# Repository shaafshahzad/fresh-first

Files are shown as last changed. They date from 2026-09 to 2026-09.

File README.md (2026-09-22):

# Fresh First

Fresh First is a phone-friendly fridge expiry tracker and low-power display
platform deployed on Vercel. Capture groceries naturally with phrases such as
`Milk tomorrow` or `Bread Sep 4`; Fresh First parses the dates and keeps the
list ordered from the soonest expiry to the latest.

[Try the web app](https://fresh-first.vercel.app) ·
[Read the build story](https://www.shaafshahzad.com/blog/fresh-first)

## Screenshots

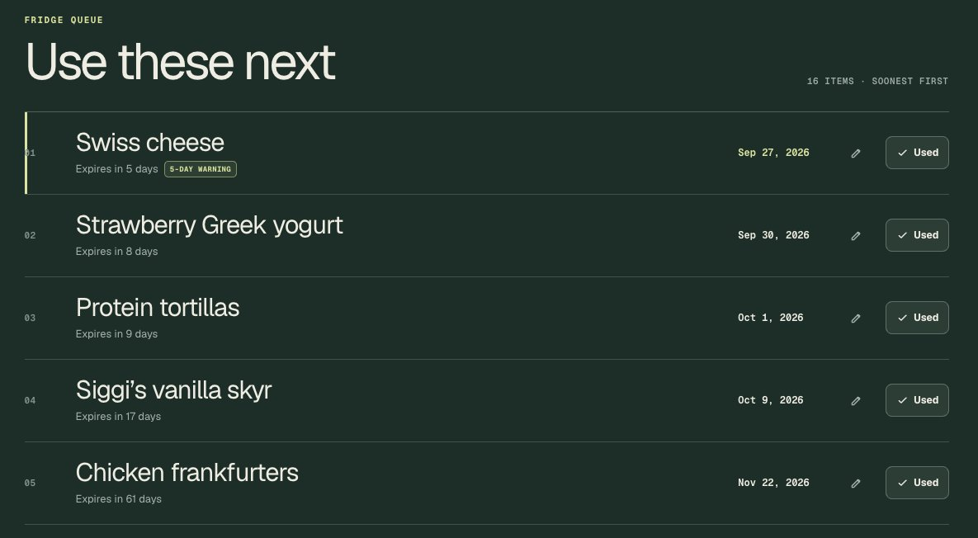
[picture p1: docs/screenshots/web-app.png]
Fresh First web app showing groceries ordered by expiry date


| Working e-paper display | Finished prototype |
| --- | --- |
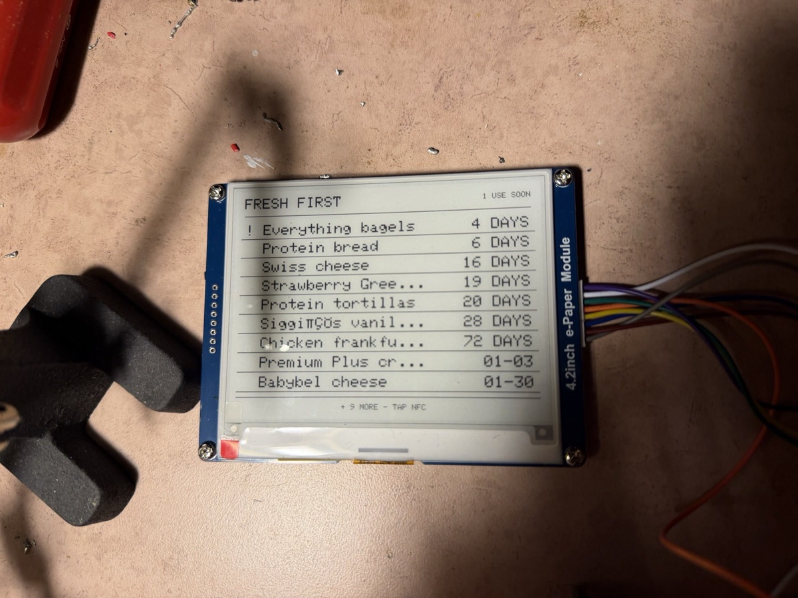
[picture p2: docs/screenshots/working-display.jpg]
Working Fresh First e-paper display showing an expiry-sorted grocery list
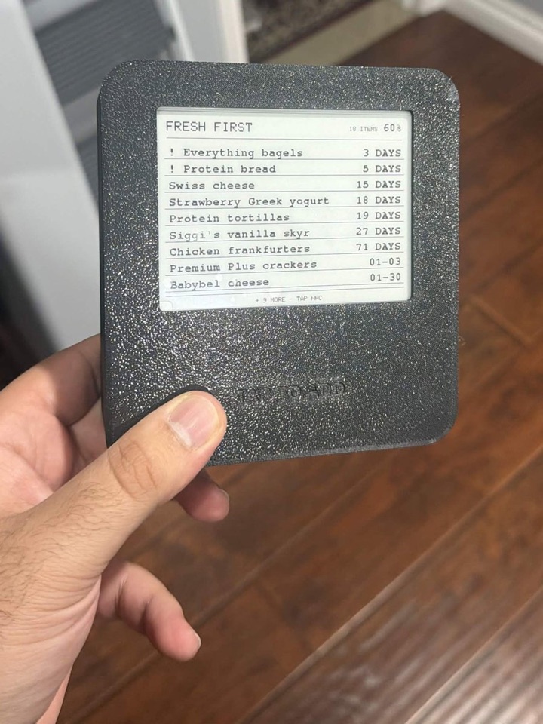
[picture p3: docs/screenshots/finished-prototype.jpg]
Finished Fresh First prototype in its 3D-printed enclosure
|  |  |

## Current MVP

- Natural-language quick capture with one item per line
- Continuous cross-browser voice capture with pause-based item separation
- Local Whisper transcription during development, including Helium support
- Batch entry for several groceries at once
- Exact product-name and date fields as a fallback
- Durable Neon Postgres storage connected through Vercel
- Email/password customer accounts with private, account-scoped fridge data
- Physical display provisioning and short-lived code pairing
- NFC handoff that opens the correct customer fridge on a phone
- Authenticated, ETag-enabled JSON feed for low-power e-paper firmware
- Automatic expiry sorting
- Clear expired, use-now, really-soon, and five-day warning states
- One-tap “Used” removal with retained history
- Inline product-name and expiry-date correction with automatic re-sorting
- Responsive management view at `/`
- Auto-refreshing fridge view at `/display`
- Customer display preview at `/display`
- Hardware feed at `/api/device/{deviceId}/feed`

Quick capture understands `today`, `tomorrow`, `Friday`, `next Friday`,
`in 3 days`, `+3 days`, `Sep 4`, `4 Sep`, `9/4`, and ISO dates.

Start a voice session once, say one product and expiry date, pause briefly, and
continue with the next item. Development audio is transcribed locally by
whisper.cpp. A deployed instance can use `OPENAI_API_KEY` directly or the
project's Vercel AI Gateway identity; recorded phrases are processed in memory
and are not stored by Fresh First.

## Development

Requirements: Node.js 22.13 or newer. Local voice transcription also requires
`ffmpeg`, `whisper-cpp`, and a compatible GGML Whisper model.

- Install dependencies: `bun install`
- Pull development variables: `vercel env pull .env.local`
- Prepare the database: `bun run db:migrate`
- Set `BETTER_AUTH_SECRET` to a high-entropy secret before production
- Load relative-date development examples: `bun run db:seed:mock`
- Provision a simulated or physical display: `bun run device:provision -- "Kitchen display"`
- Start locally: `bun run dev`
- Optional local voice model: set `WHISPER_MODEL_PATH` and
  `WHISPER_CLI_PATH` (the macOS defaults are detected automatically)
- Run checks: `bun run lint`, `bun run test`, and `bun run build`
- Deploy: `vercel --prod --yes`

The physical-device contract and NFC lifecycle are documented in
[`docs/device-protocol.md`](docs/device-protocol.md).

## Privacy

The GitHub repository is private. Customer data is separated by account,
device feeds require per-unit secrets, and pairing codes expire after 30
minutes. Environment files and database credentials are ignored by Git.

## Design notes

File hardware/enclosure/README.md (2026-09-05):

# Fresh First 4.2-inch e-paper enclosure

This is a two-piece, parameterized OpenSCAD case for the Waveshare 4.2-inch
400 × 300 e-paper module. It provides:

- a rear-loading pocket for the 103 × 78.5 mm display PCB;
- a flush removable rear cover;
- four protected pockets for 20 × 3 mm disc magnets;
- a front-facing 32.5 × 32.5 mm pocket for a 30 × 30 mm NFC tag;
- an internal cavity for a small ESP32 board and wiring; and
- a generous right-side USB/cable service opening.

The assembled shell is approximately **120 × 129.5 × 16.8 mm**. The display
window is 86.2 × 64.8 mm. All important fit values are grouped at the top of
`fresh-first-case.scad` so they can be adjusted after the physical parts arrive.

The model targets the exact module in the prototype order:

- [Waveshare 4.2-inch e-paper module on Amazon Canada](https://www.amazon.ca/dp/B074NR1SW2)
- [Waveshare module specification](https://www.waveshare.com/product/ai/displays/e-paper/4.2inch-e-paper-module.htm)

## Files

- `fresh-first-case.scad` — editable source and exploded assembly preview
- `output/fresh-first-front.stl` — front shell
- `output/fresh-first-back.stl` — magnetized rear cover
- `output/fresh-first-magnet-test.stl` — quick pocket-clearance test
- `output/fresh-first-case-preview.png` — rendered exploded interior preview
- `output/fresh-first-product-preview.png` — rendered product-front preview

## Hardware

- Waveshare 4.2-inch E-Paper Module, 103 × 78.5 mm PCB
- 4 × 20 × 3 mm neodymium disc magnets ([8-pack used for this design](https://www.amazon.ca/dp/B09XJ5JFFX))
- 1 × ferrite-backed/on-metal NFC tag, no larger than 30 × 30 × 1 mm
- 4 × M2.5 × 8 mm countersunk self-tapping screws
- thin EVA/foam dots for the four PCB corners
- two-part epoxy or E6000-style flexible adhesive for the magnets

The current magnet pocket is **20.4 mm diameter × 3.2 mm deep**, with a 0.65 mm
printed skin between each magnet and the refrigerator. Print the fit-test part
first: magnet batches and printer calibration can vary. Increase
`magnet_d_clearance` in 0.1 mm steps if needed.

The linked magnet listing must have the **20x3mm 8Pcs-Silver** size selected.
Amazon may switch the selected variation when opening a product link, so verify
that exact size before ordering. Eight magnets provide four for the enclosure
and four spares for fit testing or a second revision.

Use an **on-metal or ferrite-backed NFC tag**. A plain sticker tag may become
unreliable when mounted near a steel refrigerator and four strong magnets. The
tag pocket is on the front lower chin to maximize separation from both.

## Export

From this directory:

```sh
openscad -o output/fresh-first-front.stl \
  -D 'part="front"' fresh-first-case.scad

openscad -o output/fresh-first-back.stl \
  -D 'part="back"' fresh-first-case.scad

openscad -o output/fresh-first-magnet-test.stl \
  -D 'part="magnet_test"' fresh-first-case.scad

openscad -o output/fresh-first-product-preview.png \
  --imgsize=1200,1200 --viewall --autocenter --projection=o \
  -D 'part="product_preview"' fresh-first-case.scad
```

## Print settings

- PETG recommended; PLA is fine for the first dimensional prototype.
- 0.20 mm layer height, 0.4 mm nozzle.
- 4 perimeters, 5 top/bottom layers, 20–30% gyroid infill.
- Print the front shell face-down and the rear cover fridge-side-down.
- No supports should be needed. Bridge the right-side service opening.

## Assembly

1. Print `fresh-first-magnet-test.stl` and confirm the magnet pocket before the
   full rear cover.
2. Dry-fit the display from the rear. Do not force the glass or flex cable.
3. Bond the NFC tag inside the lower front pocket, with its readable face aimed
   through the 0.8 mm front skin.
4. Mount the ESP32 and any battery with thin VHB/foam tape after confirming the
   exact purchased board and battery dimensions.
5. Put a thin foam dot on each PCB corner so the closed rear cover holds the
   module gently without flexing it.
6. Epoxy one magnet into each rear-cover pocket. Let the adhesive cure fully.
7. Close the case with four M2.5 × 8 mm countersunk self-tapping screws. Their
   heads must sit below the rear surface so they cannot scratch the fridge.

Do not print around installed magnets. Install them only after printing, and
keep loose neodymium magnets away from children, pets, magnetic cards, and
medical implants. They are brittle and can chip or pinch when allowed to snap
together.

## Fit notes before a production enclosure

This first version uses the manufacturer's PCB dimensions and allows extra
clearance for prototype wiring. Before a production print, measure the delivered
module's screen offset, rear component height, connector location, ESP32 board,
battery, screw heads, NFC tag, and magnets with calipers, then update the grouped
parameters at the top of the SCAD file.

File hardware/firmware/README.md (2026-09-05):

# Fresh First display firmware

This PlatformIO project powers the 30-pin ESP32 DevKit and Waveshare 4.2-inch
black/white V2 e-paper prototype. It provisions Wi-Fi through a phone-friendly
captive portal, securely fetches the paired fridge feed, refreshes the panel
only when its content changes, and sleeps between checks.

The fridge view shows the nine soonest-expiring items. When more items exist,
the footer reports the hidden count and directs the user to tap the NFC tag for
the complete list.

The monochrome Waveshare V2 panel used by this prototype has an SSD1683
controller and requires the `GxEPD2_420_GDEY042T81` driver. The older
UC8176-compatible `GxEPD2_420` driver can compile and transmit without errors,
but the V2 panel ignores those frames and retains its previous image.

## Wiring

Disconnect USB power before adding or moving wires.

| Display | ESP32 |
| --- | --- |
| VCC | 3V3 |
| GND | GND |
| DIN | D14 / GPIO14 |
| CLK | D13 / GPIO13 |
| CS | D15 / GPIO15 |
| DC | D27 / GPIO27 |
| RST | D26 / GPIO26 |
| BUSY | D25 / GPIO25 |

Leave the display module's `BS` resistor in its factory four-wire SPI position.

## Build and upload

Install PlatformIO once with a pip-capable tool environment:

```sh
uv tool install platformio --with pip
```

Then, from this directory:

```sh
platformio run
platformio run \
  --target upload \
  --upload-port /dev/cu.usbserial-0001
```

For a real unit, first generate a unique device record and local credentials
header from the repository root:

```sh
bun run device:provision -- \
  --firmware-header hardware/firmware/include/device_secrets.h \
  --app-url https://fresh-first.vercel.app \
  "Kitchen display prototype"
```

The generated `device_secrets.h` is ignored by Git and created with owner-only
permissions. Never commit or paste its device secret. Rebuild and upload after
provisioning.

On first boot, the display shows a temporary Wi-Fi network named **Fresh First
XXXX**. Join it from a phone and choose the home 2.4 GHz network in the captive
portal. Once online, the display shows a pairing code. Tap the NFC tag or open
the account page, sign in, and enter that code. The display checks pairing mode
every 30 seconds and switches to the live fridge list automatically.

Normal fridge mode checks every 15 minutes and uses the feed's `ETag` to skip
unchanged e-paper refreshes. E-paper retains its image without power, and the
firmware hibernates the panel and deep-sleeps the ESP32 between checks.

If upload waits at `Connecting...`, hold the ESP32 `BOOT` button, briefly press
and release `EN`, and release `BOOT` once writing begins.

If the saved Wi-Fi is unavailable, the setup portal reopens automatically.
This prototype uses the ESP32 DevKit's onboard regulator and power LED, so its
measured battery life will be worse than a production low-power board even
while the ESP32 itself is in deep sleep.

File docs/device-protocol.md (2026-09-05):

# Fresh First display protocol

The physical display is a low-power client, not a second copy of the web app.
It wakes on a timer, requests a compact feed, paints the e-paper panel only when
the response changes, then returns to deep sleep.

## Manufacturing identity

Run `bun run device:provision -- "Kitchen display"` for each unit. Provisioning
creates:

- a public device ID such as `FF-2ABC3DEF`;
- a 256-bit secret that is written to the device once;
- an NFC URL in the form `https://fresh-first.vercel.app/d/FF-2ABC3DEF`.

Only a SHA-256 hash of the device secret is stored in the database. The raw
secret must be stored in protected firmware or a secure element and is never
printed on the enclosure or encoded in the NFC tag.

## Device feed

The device calls:

```http
GET /api/device/{deviceId}/feed
Authorization: Bearer {deviceSecret}
If-None-Match: {lastEtag}
X-Pairing-Code: {lastPairingCode}
X-Firmware-Version: {firmwareVersion}
```

An unclaimed device receives pairing mode:

```json
{
  "mode": "pairing",
  "pairingCode": "ABCD-2345",
  "expiresInSeconds": 1800,
  "nfcPath": "/d/FF-2ABC3DEF",
  "refreshAfterSeconds": 30
}
```

While the display is unclaimed, it persists the last pairing code and sends it
back in `X-Pairing-Code`. The API reuses that code until it expires instead of
invalidating a code while the customer is typing it. Pairing mode checks every
30 seconds; normal fridge mode returns to the 15-minute low-power cycle.

The display renders the pairing code until the customer claims it. Pairing
codes are short-lived, stored as keyed hashes, and require a signed-in account.

A claimed device receives fridge mode:

```json
{
  "mode": "fridge",
  "device": { "id": "FF-2ABC3DEF", "name": "Kitchen display" },
  "fridge": { "id": "...", "name": "My fridge" },
  "items": [
    {
      "id": 1,
      "name": "Milk",
      "expiresOn": "2026-09-04",
      "days": 2,
      "marker": "Really soon",
      "timing": "Expires in 2 days",
      "tone": "soon"
    }
  ],
  "refreshAfterSeconds": 900
}
```

The endpoint includes an `ETag`. If the list is unchanged, the device receives
`304 Not Modified` and can skip the expensive panel refresh. A 15-minute wake
cycle is the initial default; firmware should also refresh immediately after a
physical wake-button press.

## NFC customer flow

The NFC tag contains only the public `/d/{deviceId}` URL. It never contains the
device secret.

1. An unclaimed display sends the customer to account creation or sign-in and
   preselects that device for pairing.
2. The customer enters the code visible on the e-paper panel.
3. A claimed display sends its owner directly to the mobile quick-add area.
4. A display linked to another account reveals no fridge contents.

## Production hardening still required

Before commercial release, add verified-email delivery and password reset,
per-account pairing attempt throttles, firmware signing and secure updates,
device-secret rotation, manufacturing audit records, privacy/retention controls,
and a recovery process for resale or ownership transfer.

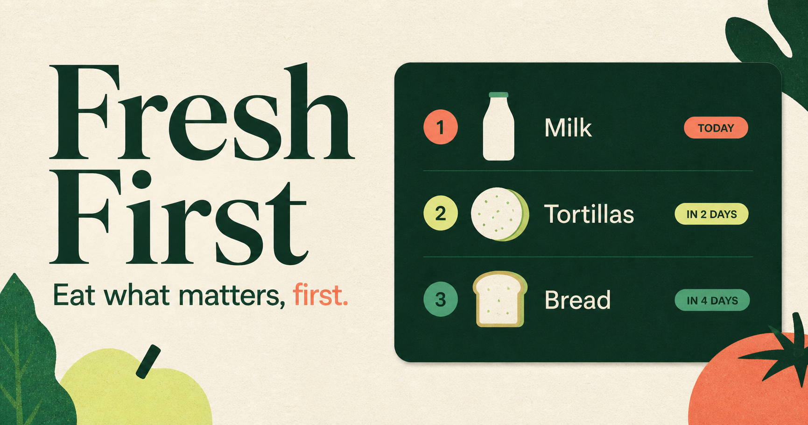
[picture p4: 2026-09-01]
public/og.png

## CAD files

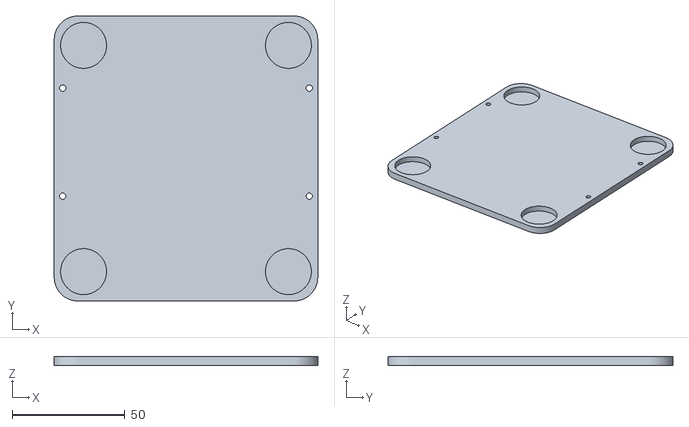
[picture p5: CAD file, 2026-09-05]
hardware/enclosure/output/fresh-first-back.stl
117.1 x 126.6 x 3.85

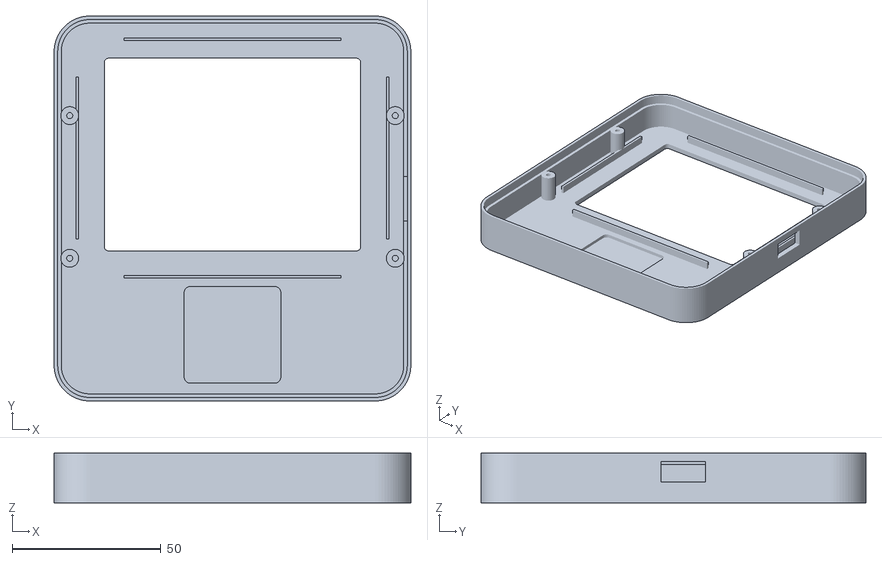
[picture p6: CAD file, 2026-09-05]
hardware/enclosure/output/fresh-first-front.stl
120.0 x 129.5 x 16.8

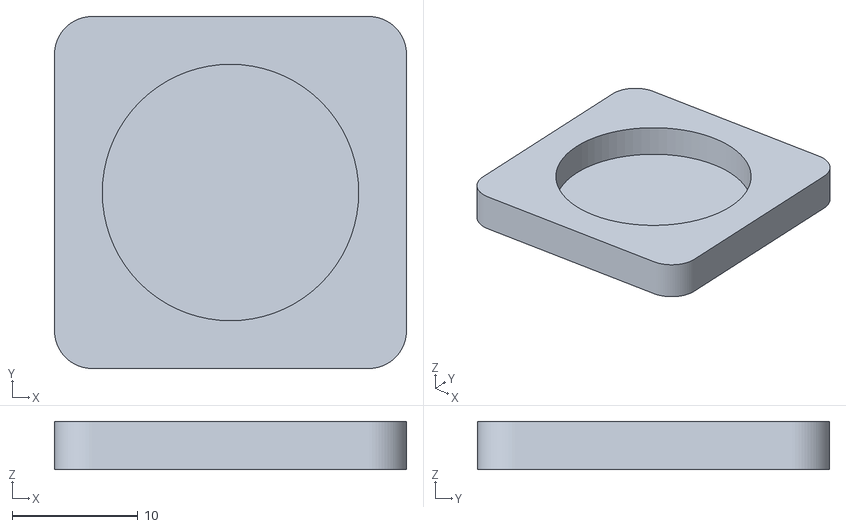
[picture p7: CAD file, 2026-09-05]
hardware/enclosure/output/fresh-first-magnet-test.stl
28.0 x 28.0 x 3.85

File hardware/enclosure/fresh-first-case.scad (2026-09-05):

/*
 * Fresh First 4.2-inch e-paper enclosure
 *
 * Designed for the Waveshare 4.2inch E-Paper Module (103 x 78.5 mm PCB),
 * four 20 x 3 mm disc magnets, and a 30 x 30 mm on-metal NFC tag.
 *
 * Export examples:
 *   openscad -o output/fresh-first-front.stl -D 'part="front"' fresh-first-case.scad
 *   openscad -o output/fresh-first-back.stl -D 'part="back"' fresh-first-case.scad
 *   openscad -o output/fresh-first-magnet-test.stl -D 'part="magnet_test"' fresh-first-case.scad
 */

$fn = 72;

// Select: "front", "back", "assembly", "product_preview", "magnet_test"
part = "assembly";

// Purchased display module
pcb_w = 103.0;
pcb_h = 78.5;
pcb_t = 1.6;
pcb_clearance = 0.55;

// Visible e-paper area. These offsets are adjustable after a physical dry fit.
window_w = 86.2;
window_h = 64.8;
window_bottom_offset = 8.0;
window_corner_r = 1.4;

// Case envelope
side_margin = 8.5;
top_margin = 8.5;
nfc_chin = 34.0;
case_w = pcb_w + (2 * side_margin);       // 120.0 mm
case_h = pcb_h + (2 * top_margin) + nfc_chin; // 129.5 mm
case_r = 12.0;
shell_depth = 16.8;
face_t = 2.2;
wall = 2.4;

// Inset rear cover
cover_t = 3.85;
cover_rebate = 1.2;
cover_clearance = 0.25;
cover_inset = cover_rebate + cover_clearance;

// Magnets: 20 x 3 mm discs, installed from the inside of the rear cover.
magnet_d = 20.0;
magnet_t = 3.0;
magnet_d_clearance = 0.40;
magnet_t_clearance = 0.20;
magnet_rear_skin = 0.65;
magnet_edge_offset = 14.5;

// NFC: accepts a 30 x 30 mm ferrite-backed/on-metal tag.
nfc_tag_w = 30.0;
nfc_tag_h = 30.0;
nfc_tag_t = 1.0;
nfc_xy_clearance = 2.5;
nfc_depth_clearance = 0.40;
nfc_front_skin = face_t - nfc_tag_t - nfc_depth_clearance;
nfc_pocket_w = nfc_tag_w + nfc_xy_clearance;
nfc_pocket_h = nfc_tag_h + nfc_xy_clearance;
nfc_pocket_r = 2.0;
nfc_pocket_x = (case_w - nfc_pocket_w) / 2;
nfc_pocket_y = 6.0;

// Module placement inside the front shell
pcb_x = (case_w - pcb_w) / 2;
pcb_y = top_margin + nfc_chin;
window_x = pcb_x + ((pcb_w - window_w) / 2);
window_y = pcb_y + window_bottom_offset;

// Four M2.5 self-tapping rear-cover screws, kept away from the magnets.
screw_d = 2.8;
screw_head_d = 5.4;
screw_head_h = 1.5;
pilot_d = 2.05;
boss_d = 6.0;
screw_x_left = 5.25;
screw_x_right = case_w - 5.25;
screw_y_low = 48.0;
screw_y_high = 96.0;
screw_points = [
    [screw_x_left, screw_y_low],
    [screw_x_left, screw_y_high],
    [screw_x_right, screw_y_low],
    [screw_x_right, screw_y_high]
];

// Generous cable/USB access slot on the right edge.
service_slot_y = pcb_y + 18.0;
service_slot_length = 15.0;
service_slot_height = 7.0;
service_slot_z = 7.0;

eps = 0.02;

module rounded_rect_2d(w, h, r) {
    hull() {
        translate([r, r]) circle(r = r);
        translate([w - r, r]) circle(r = r);
        translate([r, h - r]) circle(r = r);
        translate([w - r, h - r]) circle(r = r);
    }
}

module rounded_prism(w, h, d, r) {
    linear_extrude(height = d)
        rounded_rect_2d(w, h, r);
}

module screw_bosses() {
    for (point = screw_points) {
        difference() {
            translate([point[0], point[1], face_t])
                cylinder(d = boss_d, h = shell_depth - cover_t - face_t + 0.25);
            translate([point[0], point[1], shell_depth - cover_t - 7.0])
                cylinder(d = pilot_d, h = 7.3);
        }
    }
}

module pcb_locators() {
    locator_t = 0.9;
    locator_h = 3.1;
    inside_left = pcb_x - (pcb_clearance / 2);
    inside_right = pcb_x + pcb_w + (pcb_clearance / 2);
    inside_bottom = pcb_y - (pcb_clearance / 2);
    inside_top = pcb_y + pcb_h + (pcb_clearance / 2);

    // Short rails avoid the connector and let the board lift out during fitting.
    translate([inside_left - locator_t, pcb_y + 12, face_t])
        cube([locator_t, pcb_h - 24, locator_h]);
    translate([inside_right, pcb_y + 12, face_t])
        cube([locator_t, pcb_h - 24, locator_h]);
    translate([pcb_x + 15, inside_bottom - locator_t, face_t])
        cube([pcb_w - 30, locator_t, locator_h]);
    translate([pcb_x + 15, inside_top, face_t])
        cube([pcb_w - 30, locator_t, locator_h]);
}

module front_shell_skin() {
    difference() {
        rounded_prism(case_w, case_h, shell_depth, case_r);

        // Main electronics cavity, leaving the front face and perimeter walls.
        translate([wall, wall, face_t])
            rounded_prism(
                case_w - (2 * wall),
                case_h - (2 * wall),
                shell_depth - face_t + eps,
                max(case_r - wall, 1)
            );

        // Rebate makes the rear cover flush with the outer shell.
        translate([cover_rebate, cover_rebate, shell_depth - cover_t])
            rounded_prism(
                case_w - (2 * cover_rebate),
                case_h - (2 * cover_rebate),
                cover_t + eps,
                case_r - cover_rebate
            );

        // Display opening.
        translate([window_x, window_y, -eps])
            rounded_prism(window_w, window_h, face_t + (2 * eps), window_corner_r);

        // NFC pocket opens inside, leaving a thin plastic read-through face.
        translate([nfc_pocket_x, nfc_pocket_y, nfc_front_skin])
            rounded_prism(
                nfc_pocket_w,
                nfc_pocket_h,
                face_t - nfc_front_skin + eps,
                nfc_pocket_r
            );

        // Oversized side opening tolerates common USB-C ESP32 board variants.
        translate([
            case_w - wall - eps,
            service_slot_y,
            service_slot_z
        ])
            cube([wall + (2 * eps), service_slot_length, service_slot_height]);

        // Minimal recessed NFC cue on the lower front face.
        translate([case_w / 2, 22.0, -eps])
            linear_extrude(height = 0.38)
                text(
                    "TAP TO ADD",
                    size = 4.2,
                    halign = "center",
                    valign = "center",
                    font = "Arial:style=Bold",
                    spacing = 1.08
                );
    }
}

module front_shell() {
    union() {
        front_shell_skin();
        pcb_locators();
        screw_bosses();
    }
}

module magnet_positions() {
    for (x = [magnet_edge_offset, case_w - magnet_edge_offset])
        for (y = [magnet_edge_offset, case_h - magnet_edge_offset])
            translate([x, y, 0]) children();
}

module back_cover() {
    cover_w = case_w - (2 * cover_inset);
    cover_h = case_h - (2 * cover_inset);
    cover_r = case_r - cover_inset;

    difference() {
        translate([cover_inset, cover_inset, 0])
            rounded_prism(cover_w, cover_h, cover_t, cover_r);

        // Blind magnet pockets leave a 0.65 mm plastic skin against the fridge.
        magnet_positions()
            translate([0, 0, magnet_rear_skin])
                cylinder(
                    d = magnet_d + magnet_d_clearance,
                    h = cover_t - magnet_rear_skin + eps
                );

        // Through-holes plus recessed countersinks keep screw heads off the fridge.
        for (point = screw_points) {
            translate([point[0], point[1], -eps])
                cylinder(d = screw_d, h = cover_t + (2 * eps));
            translate([point[0], point[1], -eps])
                cylinder(
                    d1 = screw_head_d,
                    d2 = screw_d,
                    h = screw_head_h + eps
                );
        }
    }
}

module magnet_fit_test() {
    test_w = magnet_d + 8;
    difference() {
        rounded_prism(test_w, test_w, cover_t, 3);
        translate([test_w / 2, test_w / 2, magnet_rear_skin])
            cylinder(
                d = magnet_d + magnet_d_clearance,
                h = cover_t - magnet_rear_skin + eps
            );
    }
}

module assembly_preview() {
    // Front shell
    color([0.90, 0.88, 0.80, 0.72]) front_shell();

    // PCB and active display placeholders
    color([0.08, 0.25, 0.20, 0.72])
        translate([pcb_x, pcb_y, face_t + 0.15])
            cube([pcb_w, pcb_h, pcb_t]);
    color([0.96, 0.95, 0.89, 1.0])
        translate([window_x, window_y, 0.10])
            cube([window_w, window_h, 0.20]);

    // NFC tag placeholder
    color([0.13, 0.55, 0.40, 0.85])
        translate([
            (case_w - nfc_tag_w) / 2,
            nfc_pocket_y + ((nfc_pocket_h - nfc_tag_h) / 2),
            nfc_front_skin
        ])
            cube([nfc_tag_w, nfc_tag_h, nfc_tag_t]);

    // Rear cover and magnets, lifted and oriented as they sit in the shell.
    preview_gap = 10;
    translate([0, 0, shell_depth + preview_gap + cover_t])
        mirror([0, 0, 1]) {
            color([0.20, 0.20, 0.20, 0.72]) back_cover();
            color([0.68, 0.70, 0.74, 1.0])
                magnet_positions()
                    translate([0, 0, magnet_rear_skin])
                        cylinder(d = magnet_d, h = magnet_t);
        }
}
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

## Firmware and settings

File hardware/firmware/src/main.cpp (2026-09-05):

#include <Arduino.h>
#include <ArduinoJson.h>
#include <Fonts/FreeMonoBold24pt7b.h>
#include <GxEPD2_BW.h>
#include <HTTPClient.h>
#include <Preferences.h>
#include <SPI.h>
#include <WiFi.h>
#include <WiFiClientSecure.h>
#include <WiFiManager.h>
#include <esp_sleep.h>
#include <time.h>

#include "app_config.h"
#include "layout_geometry.h"
#include "root_ca.h"

#if __has_include("device_secrets.h")
#include "device_secrets.h"
#define FRESH_FIRST_PROVISIONED 1
#else
namespace device_secrets {
static constexpr char kDeviceId[] = "";
static constexpr char kDeviceSecret[] = "";
}  // namespace device_secrets
#define FRESH_FIRST_PROVISIONED 0
#endif

using app_config::pins::kBusy;
using app_config::pins::kChipSelect;
using app_config::pins::kClock;
using app_config::pins::kDataCommand;
using app_config::pins::kDataIn;
using app_config::pins::kReset;

// Waveshare's current monochrome 4.2-inch V2 panel uses the SSD1683 controller.
GxEPD2_BW<GxEPD2_420_GDEY042T81, GxEPD2_420_GDEY042T81::HEIGHT> display(
    GxEPD2_420_GDEY042T81(kChipSelect, kDataCommand, kReset, kBusy));
Preferences preferences;

static_assert(app_config::kMaximumItems == display_layout::kFridgeMaximumRows,
              "Feed capacity must match the number of rendered rows");

struct DisplayItem {
  String name;
  String expiresOn;
  String tone;
  int days = 0;
  bool hasDays = false;
};

struct FridgeFeed {
  String name;
  DisplayItem items[app_config::kMaximumItems];
  uint8_t itemCount = 0;
  uint32_t hiddenItemCount = 0;
  uint32_t refreshAfterSeconds = app_config::kDefaultRefreshSeconds;
};

void drawCentered(const String& text, int16_t y, uint8_t size) {
  int16_t boundsX = 0;
  int16_t boundsY = 0;
  uint16_t boundsWidth = 0;
  uint16_t boundsHeight = 0;
  display.setTextSize(size);
  display.getTextBounds(
      text, 0, y, &boundsX, &boundsY, &boundsWidth, &boundsHeight);
  display.setCursor((display.width() - boundsWidth) / 2, y);
  display.print(text);
}

void drawCenteredInRect(const String& text, const LayoutRect& rect,
                        uint8_t size) {
  int16_t boundsX = 0;
  int16_t boundsY = 0;
  uint16_t boundsWidth = 0;
  uint16_t boundsHeight = 0;
  display.setTextSize(size);
  display.getTextBounds(
      text, 0, 0, &boundsX, &boundsY, &boundsWidth, &boundsHeight);
  const LayoutPoint cursor = centeredTextOrigin(
      rect, {boundsX, boundsY, boundsWidth, boundsHeight});
  display.setCursor(cursor.x, cursor.y);
  display.print(text);
}

String clipped(const String& text, size_t maximumCharacters) {
  if (text.length() <= maximumCharacters) return text;
  if (maximumCharacters <= 3) return text.substring(0, maximumCharacters);
  return text.substring(0, maximumCharacters - 3) + "...";
}

void beginFrame(bool clearBeforeDrawing) {
  SPI.begin(kClock, -1, kDataIn, kChipSelect);
  display.init(0, true, 2, false);
  display.setRotation(0);
  if (clearBeforeDrawing) {
    Serial.println("Screen layout changed; clearing the panel before redraw.");
    display.clearScreen();
    display.epd2.refresh(false);
  }
  display.setFullWindow();
  display.firstPage();
}

template <typename DrawFunction>
void renderScreen(const String& screenKey, DrawFunction draw) {
  const String versionedKey = String(app_config::kScreenLayoutVersion) + ":" + screenKey;
  const String previousKey = preferences.getString("screen", "");
  if (previousKey == versionedKey) {
    Serial.println("Display content is unchanged; skipping e-paper refresh.");
    return;
  }

  const String layoutPrefix = String(app_config::kScreenLayoutVersion) + ":";
  beginFrame(!previousKey.startsWith(layoutPrefix));
  do {
    display.fillScreen(GxEPD_WHITE);
    display.setTextColor(GxEPD_BLACK);
    draw();
  } while (display.nextPage());
  display.hibernate();
  preferences.putString("screen", versionedKey);
}

void drawHeader(const String& label) {
  display.setTextSize(2);
  display.setCursor(12, display_layout::kHeaderTitleY);
  display.print("FRESH FIRST");
  display.setTextSize(1);
  const String right = clipped(label, 22);
  const int16_t desiredX = display.width() - 12 - static_cast<int16_t>(right.length() * 6);
  display.setCursor(desiredX > 210 ? desiredX : 210,
                    display_layout::kHeaderLabelY);
  display.print(right);
  display.drawFastHLine(12, display_layout::kHeaderDividerY,
                        display.width() - 24, GxEPD_BLACK);
}

void showWifiSetup(const String& accessPointName) {
  renderScreen("wifi:" + accessPointName, [&]() {
    drawHeader("SETUP");
    drawCentered("CONNECT TO WI-FI", 78, 3);
    drawCentered("On your phone, join:", 120, 2);
    const LayoutRect networkBox{38, 142,
                                static_cast<int16_t>(display.width() - 76), 48};
    display.fillRoundRect(networkBox.x, networkBox.y, networkBox.width,
                          networkBox.height, 6, GxEPD_BLACK);
    display.setTextColor(GxEPD_WHITE);
    drawCenteredInRect(accessPointName, networkBox, 2);
    display.setTextColor(GxEPD_BLACK);
    drawCentered("Choose your home Wi-Fi", 226, 2);
    drawCentered("in the page that opens.", 252, 2);
  });
}

void showPairing(const String& code) {
  renderScreen("pair:" + code, [&]() {
    drawHeader("PAIR DISPLAY");
    drawCentered("YOUR PAIRING CODE", 76, 2);
    const LayoutRect codeBox{62, 101,
                             static_cast<int16_t>(display.width() - 124), 64};
    display.fillRoundRect(codeBox.x, codeBox.y, codeBox.width, codeBox.height,
                          7, GxEPD_BLACK);
    display.setTextColor(GxEPD_WHITE);
    display.setFont(&FreeMonoBold24pt7b);
    drawCenteredInRect(code, codeBox, 1);
    display.setFont(nullptr);
    display.setTextColor(GxEPD_BLACK);
    drawCentered("Tap the NFC tag", 205, 2);
    drawCentered("Sign in, then enter this code", 235, 2);
    drawCentered("This screen updates automatically", 274, 1);
  });
}

String timingLabel(const DisplayItem& item) {
  if (!item.hasDays) return "--";
  if (item.days < 0) return "PAST";
  if (item.days == 0) return "TODAY";
  if (item.days == 1) return "1 DAY";
  if (item.days > 99) return item.expiresOn.substring(5);
  return String(item.days) + " DAYS";
}

void showFridge(const FridgeFeed& feed, const String& etag) {
  renderScreen("fridge:" + etag, [&]() {
    drawHeader(feed.name);
    if (feed.itemCount == 0) {
      drawCentered("YOUR FRIDGE IS EMPTY", 130, 2);
      drawCentered("Add an item from your phone", 170, 2);
      drawCentered("and it will appear here.", 196, 2);
      return;
    }

    for (uint8_t index = 0; index < feed.itemCount; index += 1) {
      const DisplayItem& item = feed.items[index];
      const int16_t top = display_layout::kFridgeRowStartY
          + index * display_layout::kFridgeRowStride;
      const int16_t textY = top + 4;
      const bool urgent = item.tone == "expired" || item.tone == "urgent";
      const bool warning = item.tone == "soon" || item.tone == "warning";
      const String timing = timingLabel(item);

      if (urgent) {
        display.fillRect(8, top, display.width() - 16,
                         display_layout::kFridgeRowHeight, GxEPD_BLACK);
        display.setTextColor(GxEPD_WHITE);
      } else {
        display.setTextColor(GxEPD_BLACK);
        display.drawFastHLine(8, top + display_layout::kFridgeRowHeight,
                              display.width() - 16, GxEPD_BLACK);
      }

      display.setTextSize(2);
      display.setCursor(14, textY);
      display.print(warning ? "! " : "  ");
      display.print(clipped(item.name, 18));

      const int16_t timingX = display.width() - 14 - timing.length() * 12;
      display.fillRect(timingX - 4, top + 2, timing.length() * 12 + 8, 19,
                       urgent ? GxEPD_BLACK : GxEPD_WHITE);
      display.setCursor(timingX, textY);
      display.print(timing);
      display.setTextColor(GxEPD_BLACK);
    }

    if (feed.hiddenItemCount > 0) {
      display.drawFastHLine(8, display_layout::kFridgeFooterDividerY,
                            display.width() - 16, GxEPD_BLACK);
      drawCentered("+ " + String(feed.hiddenItemCount) + " MORE - TAP NFC",
                   display_layout::kFridgeFooterTextY, 1);
    }
  });
}

void showError(const String& title, const String& detail, const String& key) {
  renderScreen("error:" + key, [&]() {
    drawHeader("RETRYING");
    drawCentered(clipped(title, 22), 116, 3);
    drawCentered(clipped(detail, 34), 164, 2);
    drawCentered("Fresh First will try again", 218, 2);
    drawCentered("automatically.", 244, 2);
  });
}

#if FRESH_FIRST_DISPLAY_DIAGNOSTIC
void showDisplayDiagnostic() {
  Serial.println("Drawing uncached display diagnostic.");
  beginFrame(true);
  do {
    display.fillScreen(GxEPD_WHITE);
    display.drawRect(4, 4, display.width() - 8, display.height() - 8,
                     GxEPD_BLACK);
    display.fillRect(18, 18, display.width() - 36, 64, GxEPD_BLACK);
    display.setTextColor(GxEPD_WHITE);
    display.setFont(&FreeMonoBold24pt7b);
    drawCenteredInRect("TEST 2468",
                       {18, 18, static_cast<int16_t>(display.width() - 36), 64},
                       1);
    display.setFont(nullptr);
    display.setTextColor(GxEPD_BLACK);
    drawCentered("FULL PANEL REDRAW", 118, 3);
    drawCentered("TOP", 165, 2);
    drawCentered("MIDDLE", 210, 2);
    drawCentered("BOTTOM " + String(app_config::kFirmwareVersion), 266, 2);
  } while (display.nextPage());
  display.hibernate();
  Serial.println("Display diagnostic finished.");
}
#endif

void sleepFor(uint32_t seconds) {
  const uint32_t boundedSeconds = constrain(seconds, 15U, 24U * 60U * 60U);
  Serial.printf("Sleeping for %lu seconds.\n",
                static_cast<unsigned long>(boundedSeconds));
  Serial.flush();
  WiFi.mode(WIFI_OFF);
  esp_sleep_enable_timer_wakeup(static_cast<uint64_t>(boundedSeconds) * 1000000ULL);
  esp_deep_sleep_start();
}

String wifiAccessPointName() {
  String suffix = device_secrets::kDeviceId;
  if (suffix.length() >= 4) suffix = suffix.substring(suffix.length() - 4);
  if (suffix.isEmpty()) {
    suffix = String(static_cast<uint32_t>(ESP.getEfuseMac()), HEX);
    const int start = suffix.length() > 4 ? suffix.length() - 4 : 0;
    suffix = suffix.substring(start);
    suffix.toUpperCase();
  }
  return "Fresh First " + suffix;
}

void wifiPortalStarted(WiFiManager* manager) {
  showWifiSetup(manager->getConfigPortalSSID());
}

bool connectWifi() {
  WiFi.mode(WIFI_STA);
  WiFiManager manager;
  manager.setAPCallback(wifiPortalStarted);
  manager.setConnectTimeout(20);
  manager.setConfigPortalTimeout(app_config::kWifiPortalTimeoutSeconds);
  manager.setWiFiAutoReconnect(true);
  const String accessPointName = wifiAccessPointName();
  return manager.autoConnect(accessPointName.c_str());
}

bool syncClock() {
  configTime(0, 0, "time.google.com", "pool.ntp.org", "time.cloudflare.com");
  const uint32_t startedAt = millis();
  while (time(nullptr) < 1700000000
         && millis() - startedAt < app_config::kClockSyncTimeoutMs) {
    delay(250);
  }
  return time(nullptr) >= 1700000000;
}

void parseFridgeFeed(JsonDocument& document, FridgeFeed& feed) {
  feed.name = String(document["fridge"]["name"] | "My fridge");
  feed.hiddenItemCount = document["hiddenItemCount"] | 0;
  feed.refreshAfterSeconds = document["refreshAfterSeconds"]
      | app_config::kDefaultRefreshSeconds;

  JsonArrayConst items = document["items"].as<JsonArrayConst>();
  for (JsonObjectConst item : items) {
    if (feed.itemCount >= app_config::kMaximumItems) break;
    DisplayItem& destination = feed.items[feed.itemCount++];
    destination.name = String(item["name"] | "Item");
    destination.expiresOn = String(item["expiresOn"] | "");
    destination.tone = String(item["tone"] | "later");
    destination.hasDays = !item["days"].isNull();
    destination.days = item["days"] | 0;
  }
}

void fetchDisplayFeed() {
  WiFiClientSecure client;
  client.setCACert(kRootCa);
  HTTPClient request;
  const String url = String(app_config::kApiBaseUrl) + "/api/device/"
      + device_secrets::kDeviceId + "/feed";
  const char* responseHeaders[] = {"ETag", "X-Refresh-After"};

  request.collectHeaders(responseHeaders, 2);
  request.setConnectTimeout(15000);
  request.setTimeout(15000);
  request.setFollowRedirects(HTTPC_STRICT_FOLLOW_REDIRECTS);
  if (!request.begin(client, url)) {
    showError("CAN'T REACH APP", "Connection could not start", "begin");
    sleepFor(app_config::kErrorRefreshSeconds);
  }

  request.addHeader("Authorization", "Bearer " + String(device_secrets::kDeviceSecret));
  request.addHeader("X-Firmware-Version", app_config::kFirmwareVersion);

  const String etag = preferences.getString("etag", "");
  const String pairingCode = preferences.getString("pairCode", "");
  if (!etag.isEmpty()) request.addHeader("If-None-Match", etag);
  if (!pairingCode.isEmpty()) request.addHeader("X-Pairing-Code", pairingCode);

  const int status = request.GET();
  Serial.printf("Feed returned HTTP %d.\n", status);
  if (status == HTTP_CODE_NOT_MODIFIED) {
    const uint32_t refresh = request.header("X-Refresh-After").toInt();
    request.end();
    sleepFor(refresh > 0 ? refresh : app_config::kDefaultRefreshSeconds);
  }

  if (status != HTTP_CODE_OK) {
    request.end();
    showError("SYNC FAILED", "The app returned an error", String(status));
    sleepFor(app_config::kErrorRefreshSeconds);
  }

  const String payload = request.getString();
  const String responseEtag = request.header("ETag");
  request.end();

  JsonDocument document;
  const DeserializationError error = deserializeJson(document, payload);
  if (error) {
    Serial.printf("JSON parsing failed: %s\n", error.c_str());
    showError("SYNC FAILED", "The response was unreadable", "json");
    sleepFor(app_config::kErrorRefreshSeconds);
  }

  const String mode = String(document["mode"] | "");
  if (mode == "pairing") {
    const String code = String(document["pairingCode"] | "");
    if (code.isEmpty()) {
      showError("PAIRING FAILED", "No pairing code received", "pairing");
      sleepFor(app_config::kErrorRefreshSeconds);
    }
    preferences.putString("pairCode", code);
    preferences.remove("etag");
    showPairing(code);
    sleepFor(document["refreshAfterSeconds"] | app_config::kPairingRefreshSeconds);
  }

  if (mode == "fridge") {
    FridgeFeed feed;
    parseFridgeFeed(document, feed);
    const String screenEtag = responseEtag.isEmpty()
        ? String(document["generatedAt"] | "updated")
        : responseEtag;
    showFridge(feed, screenEtag);
    preferences.remove("pairCode");
    if (!responseEtag.isEmpty()) preferences.putString("etag", responseEtag);
    sleepFor(feed.refreshAfterSeconds);
  }

  showError("SYNC FAILED", "Unknown display response", "mode");
  sleepFor(app_config::kErrorRefreshSeconds);
}

void setup() {
  Serial.begin(115200);
  delay(250);
  Serial.printf("Fresh First firmware %s starting.\n", app_config::kFirmwareVersion);
  preferences.begin("freshfirst", false);

#if FRESH_FIRST_DISPLAY_DIAGNOSTIC
  showDisplayDiagnostic();
  while (true) delay(1000);
#endif

#if !FRESH_FIRST_PROVISIONED
  showError("NOT PROVISIONED", "Add device_secrets.h", "unprovisioned");
  sleepFor(60 * 60);
#endif

  if (!connectWifi()) {
    showError("WI-FI NOT SET", "Setup portal timed out", "wifi");
    sleepFor(app_config::kErrorRefreshSeconds);
  }

  Serial.print("Wi-Fi connected. IP: ");
  Serial.println(WiFi.localIP());
  if (!syncClock()) {
    showError("CLOCK NOT READY", "Secure sync could not start", "clock");
    sleepFor(app_config::kErrorRefreshSeconds);
  }

  fetchDisplayFeed();
}

void loop() {
  delay(1000);
}

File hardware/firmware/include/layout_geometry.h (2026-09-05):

#pragma once

#include <stdint.h>

struct LayoutRect {
  int16_t x;
  int16_t y;
  int16_t width;
  int16_t height;
};

struct TextBounds {
  int16_t x;
  int16_t y;
  uint16_t width;
  uint16_t height;
};

struct LayoutPoint {
  int16_t x;
  int16_t y;
};

namespace display_layout {
static constexpr int16_t kHeaderTitleY = 10;
static constexpr int16_t kHeaderTitleHeight = 16;
static constexpr int16_t kHeaderLabelY = 14;
static constexpr int16_t kHeaderDividerY = 34;
static constexpr int16_t kFridgeRowStartY = 42;
static constexpr int16_t kFridgeRowHeight = 23;
static constexpr int16_t kFridgeRowStride = 25;
static constexpr uint8_t kFridgeMaximumRows = 9;
static constexpr int16_t kFridgeFooterDividerY = 272;
static constexpr int16_t kFridgeFooterTextY = 281;
static constexpr int16_t kFridgeFooterTextHeight = 8;
static constexpr int16_t kScreenHeight = 300;

static_assert(kHeaderTitleY + kHeaderTitleHeight < kHeaderDividerY,
              "Header title must not intersect its divider");
static_assert(kFridgeRowStartY
                  + (kFridgeMaximumRows - 1) * kFridgeRowStride
                  + kFridgeRowHeight
              < kFridgeFooterDividerY,
              "Fridge rows must not intersect the overflow footer");
static_assert(kFridgeFooterTextY + kFridgeFooterTextHeight <= kScreenHeight,
              "Overflow footer must fit on the display");
}  // namespace display_layout

inline LayoutPoint centeredTextOrigin(const LayoutRect& rect,
                                      const TextBounds& bounds) {
  return {
      static_cast<int16_t>(rect.x + (rect.width - bounds.width) / 2 - bounds.x),
      static_cast<int16_t>(rect.y + (rect.height - bounds.height) / 2 - bounds.y),
  };
}

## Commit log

2026-09-01 Pin Vercel to Next.js
2026-09-02 Scan the full camera view for expiry dates
2026-09-02 Add account and device data foundation
2026-09-02 Add secure low-power display pairing protocol
2026-09-03 Add printable enclosure for display prototype
    [fresh-first-back.stl, fresh-first-case.scad, fresh-first-front.stl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]
2026-09-05 fix(device): keep pairing codes stable during polling
2026-09-05 fix(hardware): stabilize Waveshare display rendering
    [layout_geometry.h, main.cpp]
